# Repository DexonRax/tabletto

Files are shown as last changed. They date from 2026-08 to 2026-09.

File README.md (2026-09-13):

# Tabletto V1S

> A ridiculously fast DIY osu! "tablet" built around a **SCARA arm** mechanism, powered by an **RP2040** (RP2040-Zero) and **dual AS5600 magnetic rotary encoders**.

Tabletto V1S was designed with one goal in mind: **the lowest possible input latency** using inexpensive, easy-to-source components, fully 3D printed mechanics, and custom open-source PCBs.

---

# Gallery

Tabletto image

---

# Features

* ⚡ **1000 Hz report rate** (1 ms USB HID polling)
* 🎯 Minimal cursor jitter
* 🚀 Faster than most commercial graphics tablets
* 🖨️ Fully 3D printable mechanical design
* 🔩 Custom open-source **KiCad PCBs** (base + arm sensor board)
* 🧠 On-device forward kinematics — standalone, works with **OpenTabletDriver**
* 🔘 Physical button: **short press** toggles the tablet, **hold 3 s** to calibrate
* 💾 Calibration stored in the RP2040's flash, survives power cycles

---

# How it works

Tabletto uses a **SCARA (Selective Compliance Assembly Robot Arm)** mechanism.

Two **AS5600 magnetic rotary encoders** measure the angle of each arm joint — one lives on the base PCB, the other on a small board at the elbow. The RP2040 firmware reads both encoders over two separate I2C buses and computes the pen position with forward kinematics, then sends it to the host as a vendor-defined HID report.

Because the sensors provide high-resolution angle measurements and the mechanism has very little moving mass, the result is an extremely responsive pointing device well suited for rhythm games like osu!.

---

# Hardware

Required components:

| Quantity | Part |
| --- | --- |
| 1 | RP2040-Zero (or similar module) |
| 2 | AS5600 Magnetic Rotary Encoder  |
| 2 | MR128ZZ 8x12x3.5mm Bearings |
| 4 | 4.7kΩ Resistor |
| 1 | 100nF Capacitor |
| 1 | JST XH 2.54mm straight connector|
| 1 | JST XH 2.54mm male cable |
| 1 | Keyboard Switch |
| 4 | 10mm M3 Screws |
| 2 | 4x3mm Diametral magnets |
| — | 3D Printed Parts |
| — | PCBs - from `V1S/pcb` |

Both boards have **3.2 mm M3 mounting holes**.

---

# PCBs

The electronic design is open source and lives in [V1S/pcb](V1S/pcb):

* **`pcb/base`** — base board: RP2040-Zero module, one AS5600, 4.7kΩ I2C pull-ups, calibration button, and a 4-pin connector to the arm board.
* **`pcb/arm`** — elbow board: the second AS5600 with a 100 nF decoupling cap, connected over a short 4-pin cable.

Open the `.kicad_sch` / `.kicad_pcb` files in KiCad 8+ and order them from any PCB fab (both boards are two-layer).

## Firmware pin mapping

| Function | Pin  |
| --- | ---- |
| I2C0 SDA (base) | GP0  |
| I2C0 SCL (base) | GP1  |
| I2C1 SDA (arm)  | GP2  |
| I2C1 SCL (arm)  | GP3  |
| Calibration btn | GP4  |

---

# Firmware

Located in [V1S/firmware](V1S/firmware). Built with the **Raspberry Pi Pico SDK** and **TinyUSB**.

## Flashing (easiest)

A precompiled build is included at `V1S/firmware/precompiled/tabletto.uf2`:

1. Plug the RP2040-Zero into USB while holding **BOOT**
2. Drag and drop `tabletto.uf2` onto the USB drive that appears
3. Done — the device enumerates as a HID tablet (VID `0x1209`, PID `0x0001`)

## Building from source

Requires the Pico SDK and CMake:

```
cd V1S/firmware
cmake -B build -DPICO_SDK_PATH=/path/to/pico-sdk
make -C build
```

The resulting `build/tabletto.uf2` can be flashed as above.

---

# Driver

Tabletto exposes a standard vendor-defined HID report, so **no custom driver is needed** — just use [OpenTabletDriver](https://github.com/OpenTabletDriver/OpenTabletDriver).

Import the configuration from `V1S/driver/OpenTabletDriver Configuration/TablettoV1S.json` 
into OpenTabletDriver (restart needed): 
- Linux: ~/.local/share/OpenTabletDriver/Configurations/ (create it if missing: mkdir -p ~/.local/share/OpenTabletDriver/Configurations)
- Windows: %LOCALAPPDATA%\OpenTabletDriver\Configurations

It defines:
* Work area: **180 × 112.5 mm** (X 0–18000, Y 0–11250, 0.01 mm units)
* Input report length: 9 bytes
* `libinputoverride: 1` for reliable Linux behavior

---

# Calibration

1. With the tablet connected, **pull the arm straight down** (toward you), so both sensors read their reference position.
2. **Hold the button for 3 seconds.**
3. Short-press the button at any time to toggle the tablet on/off.

Direction tuning lives in the firmware (`X_DIR` / `Y_DIR` in `main.c`) if the axes ever need flipping.

---

# Why SCARA?

Unlike traditional graphics tablets, Tabletto directly measures arm angles with magnetic encoders.

Advantages include:

* extremely low latency
* high update rate
* no pressure to use specialized tablet hardware
* inexpensive components
* entirely repairable and printable

---

# 3D Printing

All `.stl` files can be found in [V1S/models](V1S/models):

| File | Purpose |
| --- | --- |
| `arm1_up.stl` | Arm segment 1 (magnet-up variant) |
| `arm1_down.stl` | Arm segment 1 (magnet-down variant) |
| `arm2.stl` | Arm segment 2 (elbow to pen) |
| `base_down_workarea.stl` | Bottom side of the base |
| `base_up_debug.stl` | Upper side of the base (debug has a cutout for RP2040 buttons) |
| `workarea.stl` | Flat work area plate |
| `offset_nib_3.6mm.stl` | Nut-like offset for spacing (6 needed) |

Every structural component is designed to be **3D printed** — no CNC machining or laser cutting required. Place the magnets that came with the AS5600s on top of the bearings.

---

# Repository layout

```
V1S/
├── driver/    OpenTabletDriver configuration (JSON)
├── firmware/  RP2040 firmware (Pico SDK + TinyUSB) + precompiled UF2
├── models/    3D printable STL files
└── pcb/       KiCad sources: base board + arm sensor board
```

---

# License

Copyright (C) 2026 Dexon Rax

Tabletto is free and open source (AGPLv3) for personal and noncommercial
use — this covers the RP2040 firmware, the OpenTabletDriver configuration,
the 3D printable models, and the KiCad PCB sources.

💡 Want to manufacture or sell Tabletto commercially, or use it in a
closed product? Contact me for licensing — see LICENSE-COMMERCIAL.md.

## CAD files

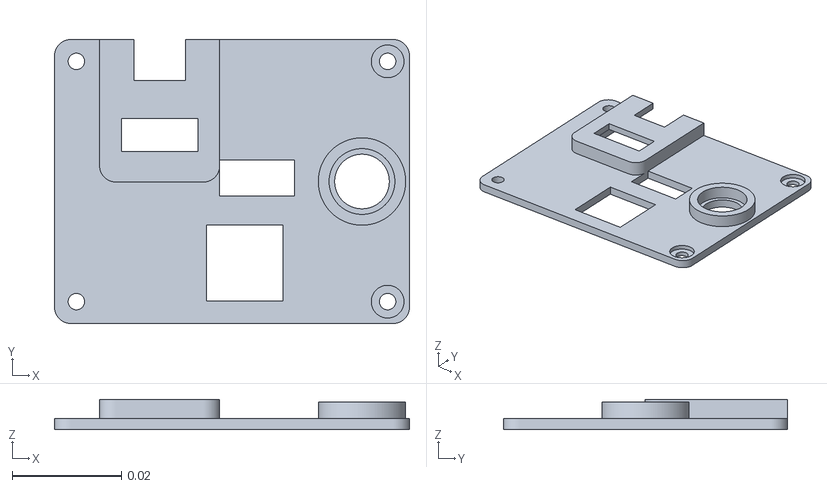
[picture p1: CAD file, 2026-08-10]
V1S/models/base_up_debug.stl
0.065 x 0.052 x 0.0055

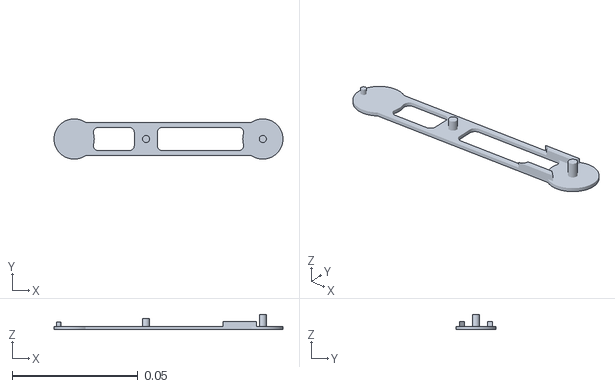
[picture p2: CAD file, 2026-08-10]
V1S/models/arm1_up.stl
0.091 x 0.016 x 0.006

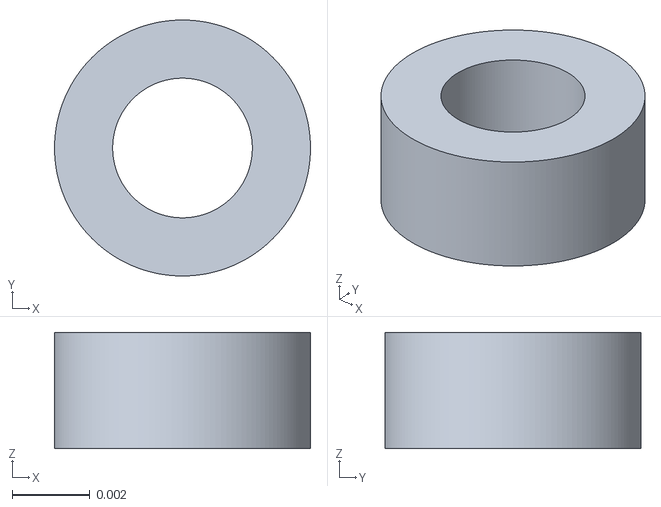
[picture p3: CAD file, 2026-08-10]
V1S/models/offset_nib_3.6mm.stl
0.0066 x 0.0066 x 0.003

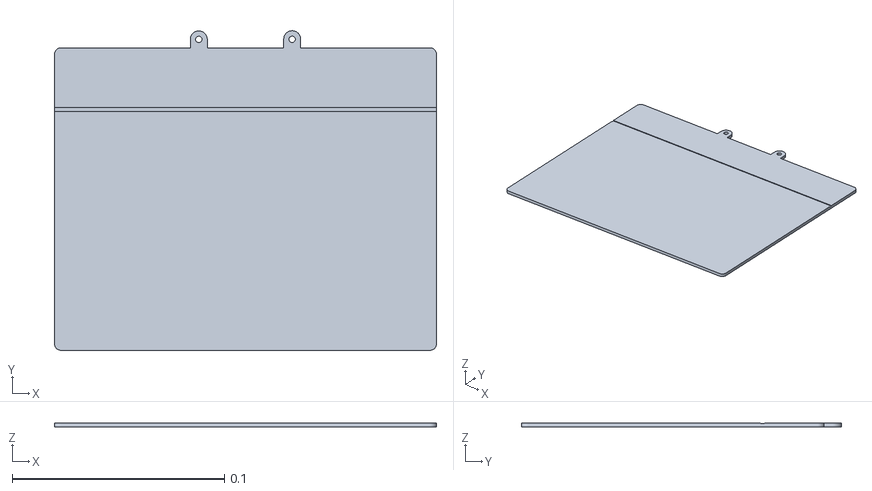
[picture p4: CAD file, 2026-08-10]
V1S/models/workarea.stl
0.18 x 0.151 x 0.002

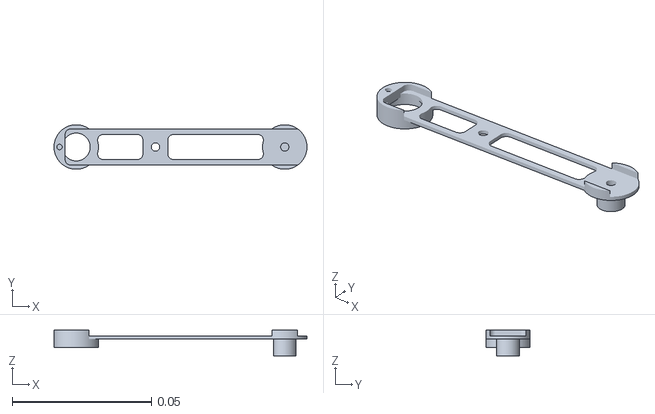
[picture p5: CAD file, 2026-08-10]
V1S/models/arm1_down.stl
0.091 x 0.016 x 0.0092

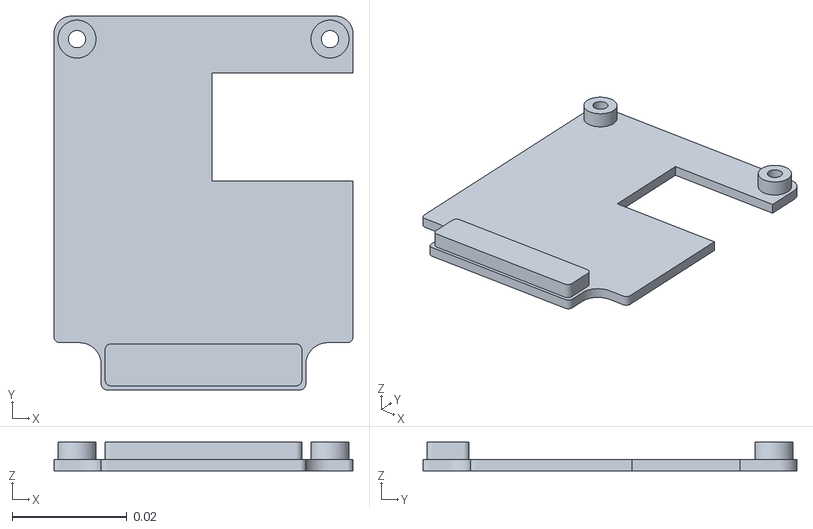
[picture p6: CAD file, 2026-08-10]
V1S/models/base_down_workarea.stl
0.052 x 0.065 x 0.005

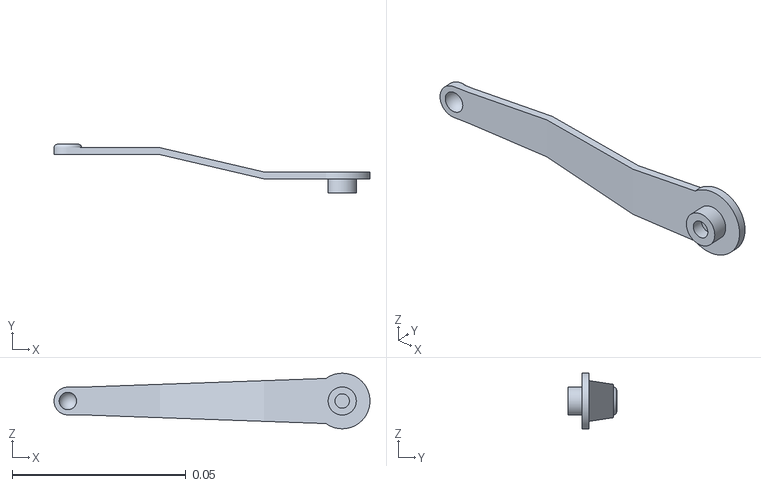
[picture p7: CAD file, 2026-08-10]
V1S/models/arm2.stl
0.091 x 0.014 x 0.016

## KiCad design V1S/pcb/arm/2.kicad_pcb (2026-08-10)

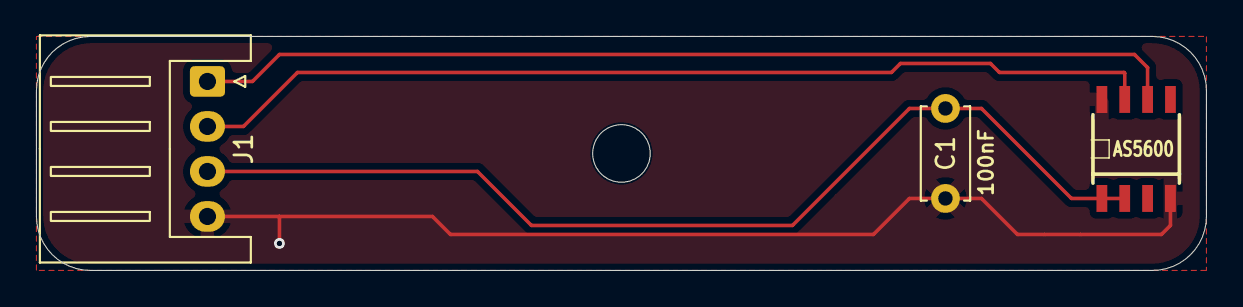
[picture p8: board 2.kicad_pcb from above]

Board: 2 copper layers, 65.0 x 13.0 mm, 3 parts (0 on the bottom side), 4 nets.

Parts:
AS5600: AS5600; SOIC8
C1: 100nF; C_Disc_D5.0mm_W2.5mm_P5.00mm
J1: Conn_01x04_Pin; JST_XH_S4B-XH-A_1x04_P2.50mm_Horizontal

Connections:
unnamed: AS5600.6 (SDA), J1.1
unnamed: AS5600.7 (SCL), J1.2
unnamed: AS5600.1 (VDD5V), AS5600.2 (VDD3V3), C1.1, J1.3
unnamed: AS5600.4 (GND), AS5600.8 (DIR), C1.2, J1.4

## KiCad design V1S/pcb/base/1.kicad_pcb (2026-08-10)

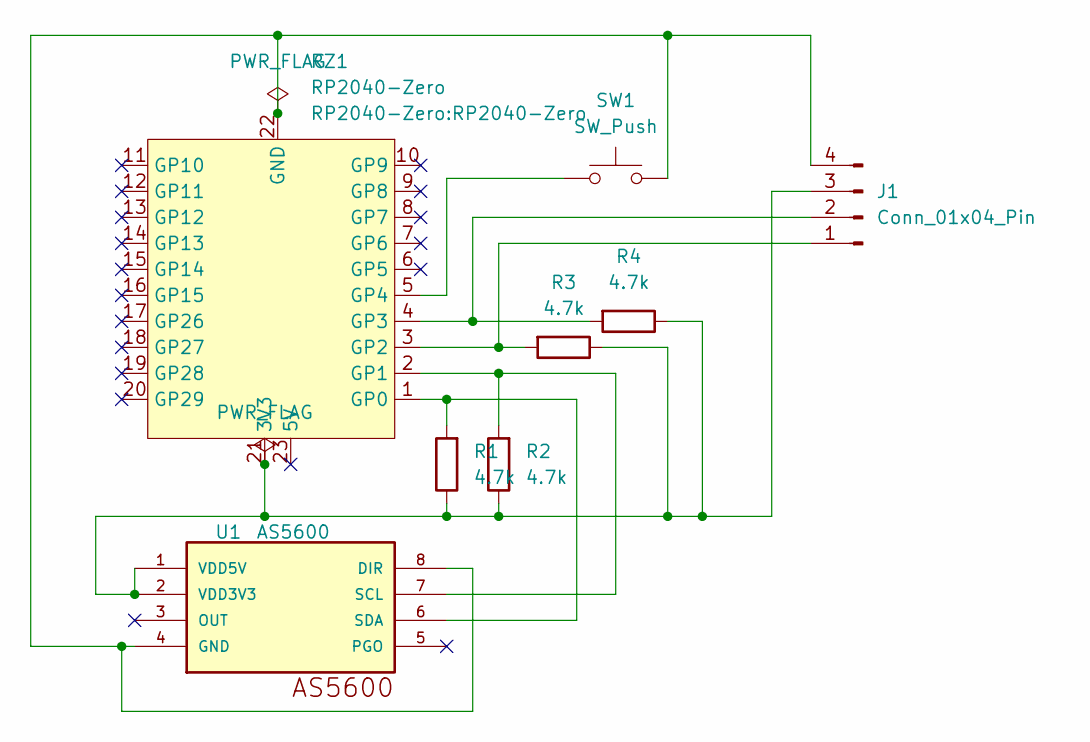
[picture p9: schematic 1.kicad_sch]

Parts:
J1: Conn_01x04_Pin; JST_XH_B4B-XH-A_1x04_P2.50mm_Vertical
R1, R2, R3, R4: 4.7k; R_Axial_DIN0207_L6.3mm_D2.5mm_P7.62mm_Horizontal
RZ1: RP2040-Zero
SW1: SW_Push; SW_Cherry_MX_1.00u_PCB
U1: AS5600; SOIC8

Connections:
unnamed: J1.1, R3.2, RZ1.3 (GP2)
unnamed: J1.2, R4.2, RZ1.4 (GP3)
unnamed: J1.3, R1.1, R2.1, R3.1, R4.1, RZ1.21 (3V3), U1.1 (VDD5V), U1.2 (VDD3V3)
unnamed: J1.4, RZ1.22 (GND), SW1.2, U1.4 (GND), U1.8 (DIR)
unnamed: R1.2, RZ1.1 (GP0), U1.6 (SDA)
unnamed: R2.2, RZ1.2 (GP1), U1.7 (SCL)
unnamed: RZ1.5 (GP4), SW1.1

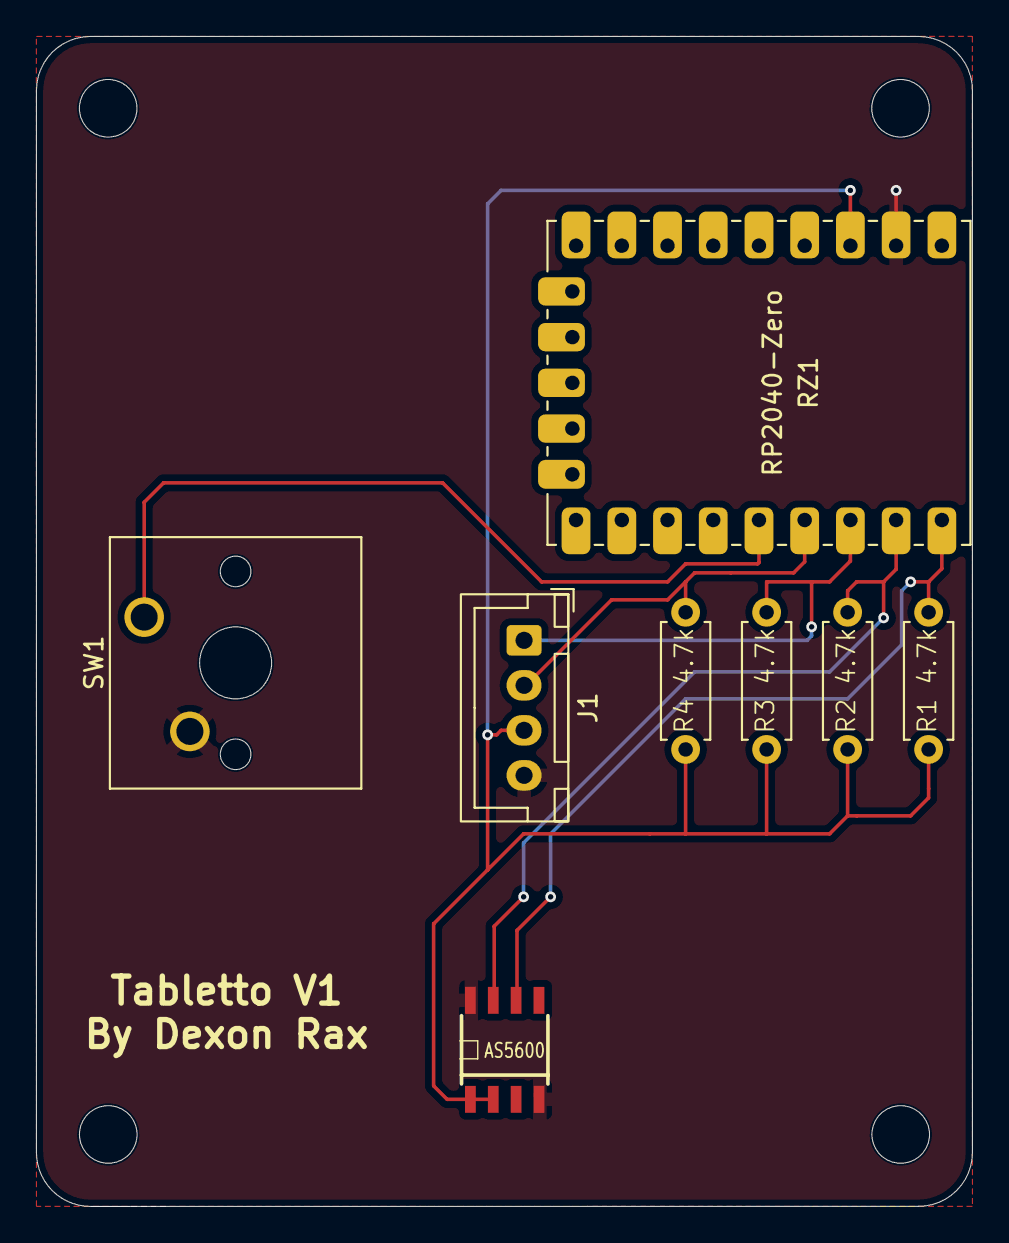
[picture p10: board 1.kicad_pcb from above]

Board: 2 copper layers, 52.0 x 65.0 mm, 8 parts (0 on the bottom side), 7 nets.

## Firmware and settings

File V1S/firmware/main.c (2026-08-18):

// Tabletto V1S firmware - RP2040 SCARA tablet
// Copyright (C) 2026 Dexon Rax <dexonrax@gmail.com>
// SPDX-License-Identifier: AGPL-3.0-or-later
//
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
#include <math.h>
#include <stdio.h>
#include <string.h>
#include "pico/stdlib.h"
#include "hardware/i2c.h"
#include "tusb.h"
#include "tablet_protocol.h"
#include "calib_store.h"

#define I2C0_SDA_PIN  0
#define I2C0_SCL_PIN  1
#define I2C1_SDA_PIN  2
#define I2C1_SCL_PIN  3
#define I2C_BAUD      400000

#define CALIB_BUTTON_PIN 4
#define CALIB_HOLD_MS    3000

#define AS5600_ADDR        0x36
#define REG_RAW_ANGLE_H    0x0C
#define I2C_TIMEOUT_US     1000

static void i2c_recover(i2c_inst_t *bus) {
    uint sda_pin = (bus == i2c0) ? I2C0_SDA_PIN : I2C1_SDA_PIN;
    uint scl_pin = (bus == i2c0) ? I2C0_SCL_PIN : I2C1_SCL_PIN;

    i2c_deinit(bus);

    gpio_init(scl_pin);
    gpio_set_dir(scl_pin, GPIO_OUT);
    gpio_put(scl_pin, 1);

    gpio_init(sda_pin);
    gpio_set_dir(sda_pin, GPIO_IN);
    gpio_pull_up(sda_pin);

    for (int i = 0; i < 9; i++) {
        if (gpio_get(sda_pin)) break;
        gpio_put(scl_pin, 0);
        busy_wait_us_32(5);
        gpio_put(scl_pin, 1);
        busy_wait_us_32(5);
    }

    gpio_set_dir(sda_pin, GPIO_OUT);
    gpio_put(sda_pin, 0);
    gpio_put(scl_pin, 1);
    busy_wait_us_32(5);
    gpio_put(sda_pin, 1);

    i2c_init(bus, I2C_BAUD);
    gpio_set_function(sda_pin, GPIO_FUNC_I2C);
    gpio_set_function(scl_pin, GPIO_FUNC_I2C);
}

static bool as5600_read_raw(i2c_inst_t *bus, uint16_t *out) {
    uint8_t reg = REG_RAW_ANGLE_H;
    uint8_t buf[2];
    if (i2c_write_timeout_us(bus, AS5600_ADDR, &reg, 1, true, I2C_TIMEOUT_US) != 1) {
        i2c_recover(bus);
        return false;
    }
    if (i2c_read_timeout_us(bus, AS5600_ADDR, buf, 2, false, I2C_TIMEOUT_US) != 2) {
        i2c_recover(bus);
        return false;
    }
    *out = ((uint16_t)(buf[0] & 0x0F) << 8) | buf[1];
    return true;
}

#define LINK1_MM 77.0f
#define LINK2_MM 77.0f
#define REACH_MM (LINK1_MM + LINK2_MM)

#define WORKSPACE_WIDTH_MM   180.0f
#define WORKSPACE_HEIGHT_MM  112.5f
#define WORKSPACE_Y_OFFSET_MM 39.0f

#define MAX_X_COORD 18000
#define MAX_Y_COORD 11250

#define X_DIR (-1.0f)
#define Y_DIR ( 1.0f)

static inline uint16_t wrap12(int32_t v) {
    v %= 4096;
    if (v < 0) v += 4096;
    return (uint16_t) v;
}

static calib_data_t calib;
static tablet_report_t report;
static bool tablet_enabled = true;

static void do_calibration(uint16_t raw0, uint16_t raw1) {
    calib.magic = CALIB_MAGIC;
    calib.offset0 = raw0;
    calib.offset1 = raw1;
    calib_save(&calib);

    gpio_put(PICO_DEFAULT_LED_PIN, 0);
    for (int i = 0; i < 6; i++) {
        gpio_put(PICO_DEFAULT_LED_PIN, !gpio_get(PICO_DEFAULT_LED_PIN));
        sleep_ms(100);
    }
    gpio_put(PICO_DEFAULT_LED_PIN, tablet_enabled);
}

static void handle_calib_button(uint32_t now_ms, bool sensors_ok, uint16_t raw0, uint16_t raw1) {
    static uint32_t press_start_ms = 0;
    static bool triggered = false;

    bool pressed = !gpio_get(CALIB_BUTTON_PIN); // active low

    if (pressed) {
        if (press_start_ms == 0) {
            press_start_ms = now_ms;
        } else if (!triggered && sensors_ok && (now_ms - press_start_ms >= CALIB_HOLD_MS)) {
            triggered = true;
            do_calibration(raw0, raw1);
        }
    } else {
        if (press_start_ms != 0 && !triggered) {
            tablet_enabled = !tablet_enabled;
            gpio_put(PICO_DEFAULT_LED_PIN, tablet_enabled);
        }
        press_start_ms = 0;
        triggered = false;
    }
}

static void forward_kinematics(float theta1, float theta2, float *x_mm, float *y_mm) {
    *x_mm = LINK1_MM * cosf(theta1) + LINK2_MM * cosf(theta1 + theta2);
    *y_mm = LINK1_MM * sinf(theta1) + LINK2_MM * sinf(theta1 + theta2);
}

static uint16_t clamp_coord(float v, uint16_t maxv) {
    if (v < 0) return 0;
    if (v > maxv) return maxv;
    return (uint16_t) v;
}

static void update_and_send_report(void) {
    uint16_t raw0, raw1;
    bool ok0 = as5600_read_raw(i2c0, &raw0);
    bool ok1 = as5600_read_raw(i2c1, &raw1);

    uint32_t now_ms = to_ms_since_boot(get_absolute_time());
    handle_calib_button(now_ms, ok0 && ok1, raw0, raw1);

    if (!tablet_enabled) return;

    if (!ok0 || !ok1) {
        report.buttons = 0;
        if (tud_hid_ready()) tud_hid_report(2, &report, sizeof(report));
        return;
    }

    uint16_t cal0 = wrap12((int32_t) raw0 - (int32_t) calib.offset0);
    uint16_t cal1 = wrap12((int32_t) raw1 - (int32_t) calib.offset1);

    float theta1 = cal0 * (2.0f * (float) M_PI / 4096.0f);
    float theta2 = -cal1 * (2.0f * (float) M_PI / 4096.0f);

    float x_mm, y_mm;
    forward_kinematics(theta1, theta2, &x_mm, &y_mm);

    float sx = X_DIR * y_mm;
    float sy = Y_DIR * x_mm;

    float nx = (sx + WORKSPACE_WIDTH_MM * 0.5f) / WORKSPACE_WIDTH_MM * MAX_X_COORD;
    float ny = (sy - WORKSPACE_Y_OFFSET_MM) / WORKSPACE_HEIGHT_MM * MAX_Y_COORD;

    report.buttons   = 0x00;
    report.x         = clamp_coord(nx, MAX_X_COORD);
    report.y         = clamp_coord(ny, MAX_Y_COORD);
    report.pressure  = 0x0000;
    report.pad       = 0;

    if (tud_hid_ready()) {
        tud_hid_report(2, &report, sizeof(report));
    }
}

int main(void) {
    stdio_init_all();
    tusb_init();

    gpio_init(PICO_DEFAULT_LED_PIN);
    gpio_set_dir(PICO_DEFAULT_LED_PIN, GPIO_OUT);
    gpio_put(PICO_DEFAULT_LED_PIN, tablet_enabled);

    gpio_init(CALIB_BUTTON_PIN);
    gpio_set_dir(CALIB_BUTTON_PIN, GPIO_IN);
    gpio_pull_up(CALIB_BUTTON_PIN);

    i2c_init(i2c0, I2C_BAUD);
    gpio_set_function(I2C0_SDA_PIN, GPIO_FUNC_I2C);
    gpio_set_function(I2C0_SCL_PIN, GPIO_FUNC_I2C);

    i2c_init(i2c1, I2C_BAUD);
    gpio_set_function(I2C1_SDA_PIN, GPIO_FUNC_I2C);
    gpio_set_function(I2C1_SCL_PIN, GPIO_FUNC_I2C);

    if (!calib_load(&calib)) {
        calib.magic = CALIB_MAGIC;
        calib.offset0 = 0;
        calib.offset1 = 0;
    }

    memset(&report, 0, sizeof(report));

    const uint32_t REPORT_INTERVAL_MS = 1;
    uint32_t last_report_ms = 0;

    while (true) {
        tud_task();

        uint32_t now_ms = to_ms_since_boot(get_absolute_time());
        if (now_ms - last_report_ms >= REPORT_INTERVAL_MS) {
            last_report_ms = now_ms;
            update_and_send_report();
        }
    }
}

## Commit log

2026-07-19 Clean up AI generated readme mistake
    Updated the description of the Arduino Pro Micro functionality to include the Python driver and clarify the cursor position mapping.
2026-07-19 Add note on DIR and GND connection for sensors
    Emphasize the importance of connecting DIR and GND on the sensors.
2026-08-10 feat!: replace Arduino/Python V1 with RP2040 V1S (KiCad PCBs, Pico firmware, OpenTabletDriver config)
    [1.kicad_pcb, 1.kicad_sch, 2.kicad_pcb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]
2026-08-18 Fix I2C reads hanging when a sensor is unplugged
    [main.c]
2026-09-13 Update bearing specifications in README
2026-09-13 Update magnet description in README

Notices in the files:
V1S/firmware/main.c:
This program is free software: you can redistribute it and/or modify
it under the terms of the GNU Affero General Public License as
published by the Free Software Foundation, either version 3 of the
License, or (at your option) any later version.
